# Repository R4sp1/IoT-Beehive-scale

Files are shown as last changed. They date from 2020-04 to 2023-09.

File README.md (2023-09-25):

# IoT Beehive scale :honeybee:

### What is it?

  The aim of this graduation work is to manufacture bee hive weight measuring equipment with
  information transfer via Internet of Things network Sigfox. It deals with Internet of Things
  technology, weight sensors, energy saving in battery powered devices, PCB designing in the
  EAGLE program and the production of device to monitor the current weight, temperature and
  humidity inside and around the bee hive. Information processing is provided by
  microcontroller ATmega 328U placed on the Arduino pro mini and programmed in Wiring
  language in Arduino IDE.

### Why is it?

  The repository contains code for my high school graduation project and the SOČ competition (High school project competition).

### Co je to?

  Cílem této maturitní práce je výroba zařízení pro měření hmotnosti včelího úlu s přenosem
  informací pomocí sítě internetu věcí Sigfox. Zabývá se technologií internetu věcí, váhových
  senzorů, úsporou energie v rámci napájení na baterii, návrhem plošného spoje v programu
  EAGLE a výrobou funkčního zařízení pro sledování aktuální váhy, teploty a vlhkosti uvnitř
  a v okolí včelího úlu. Zpracování informací je zajištěno mikrokontrolerem ATmega 328U
  umístěném na Arduinu pro mini a naprogramovaném v jazyce Wiring v programu Arduino
  IDE.

### Proč je to?

  Repozitář obsahuje kód k maturitnímu projektu a k soutěži SOČ.

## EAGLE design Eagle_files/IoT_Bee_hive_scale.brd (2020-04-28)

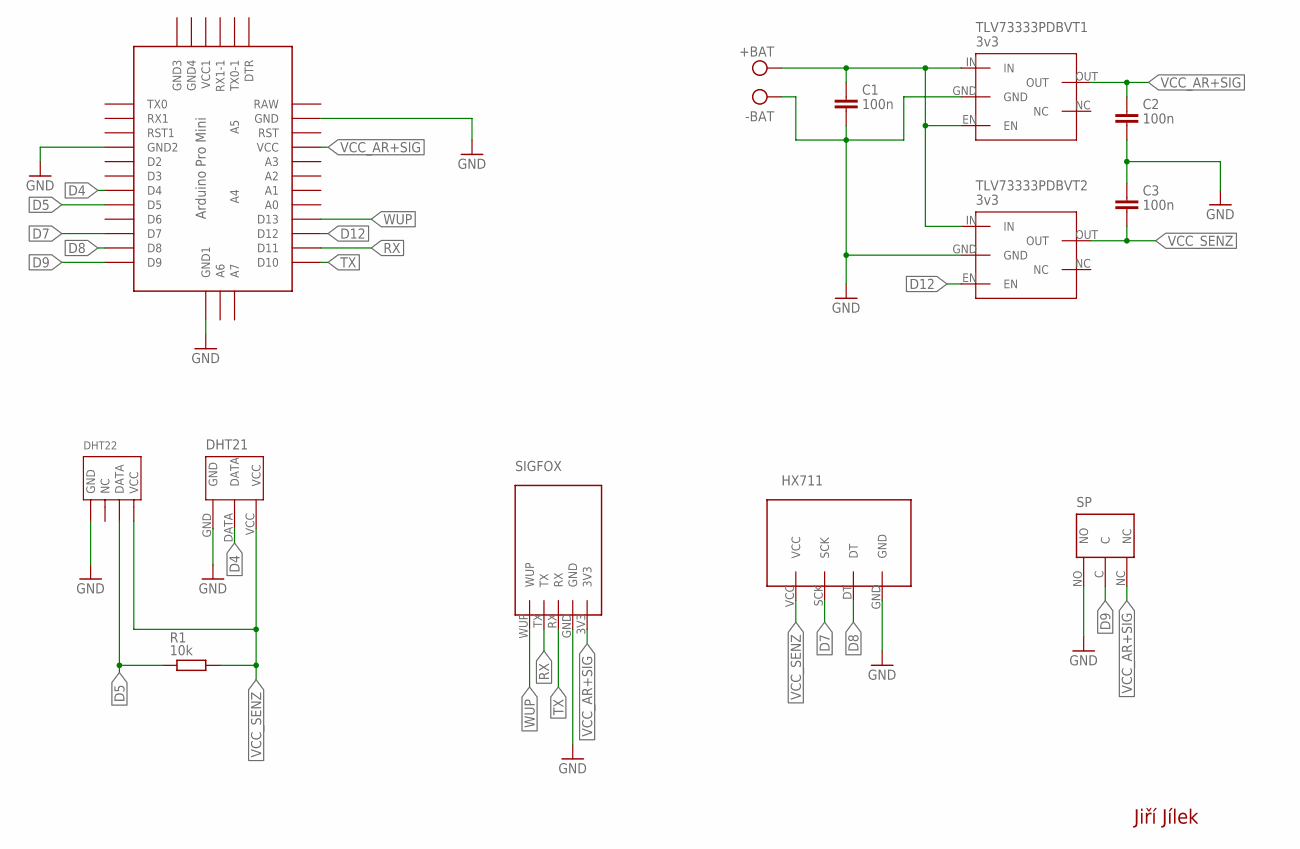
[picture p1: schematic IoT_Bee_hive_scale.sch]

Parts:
+BAT: 3.7V; AK300/2
C1, C2, C3: 100n; C1206
DHT21: 0; DHT21
DHT22: DHT22
HX711: 0; HX711
R1: 10k; R0805
SIGFOX: 0; SIGFOX_NODE
SP: 0; MIKROSP
TLV73333PDBVT1, TLV73333PDBVT2: 3v3; SOT95P280X145-5N
U$1: ABK-PRO-MINI

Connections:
D4: DHT21.DATA, U$1.D4
D5: DHT22.DATA, R1.1, U$1.D5
D7: HX711.SCK, U$1.D7
D8: HX711.DT, U$1.D8
D9: SP.C, U$1.D9
D12: TLV73333PDBVT2.EN, U$1.D12
GND: +BAT.2, C1.2, C2.2, C3.1, DHT21.GND, DHT22.GND, HX711.GND, SIGFOX.GND, SP.NO, TLV73333PDBVT1.GND, TLV73333PDBVT2.GND, U$1.GND, U$1.GND1 (GND2), U$1.GND4 (GND1)
RX: SIGFOX.TX, U$1.D11
TX: SIGFOX.RX, U$1.D10
VCC: +BAT.1, C1.1, TLV73333PDBVT1.EN, TLV73333PDBVT1.IN, TLV73333PDBVT2.IN
VCC_AR+SIG: C2.1, SIGFOX.3V3, SP.NC, TLV73333PDBVT1.OUT, U$1.VCC
VCC_SENZ: C3.2, DHT21.VCC, DHT22.VCC, HX711.VCC, R1.2, TLV73333PDBVT2.OUT
WUP: SIGFOX.WUP, U$1.D13

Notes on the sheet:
+BAT
-BAT
Jiří Jílek

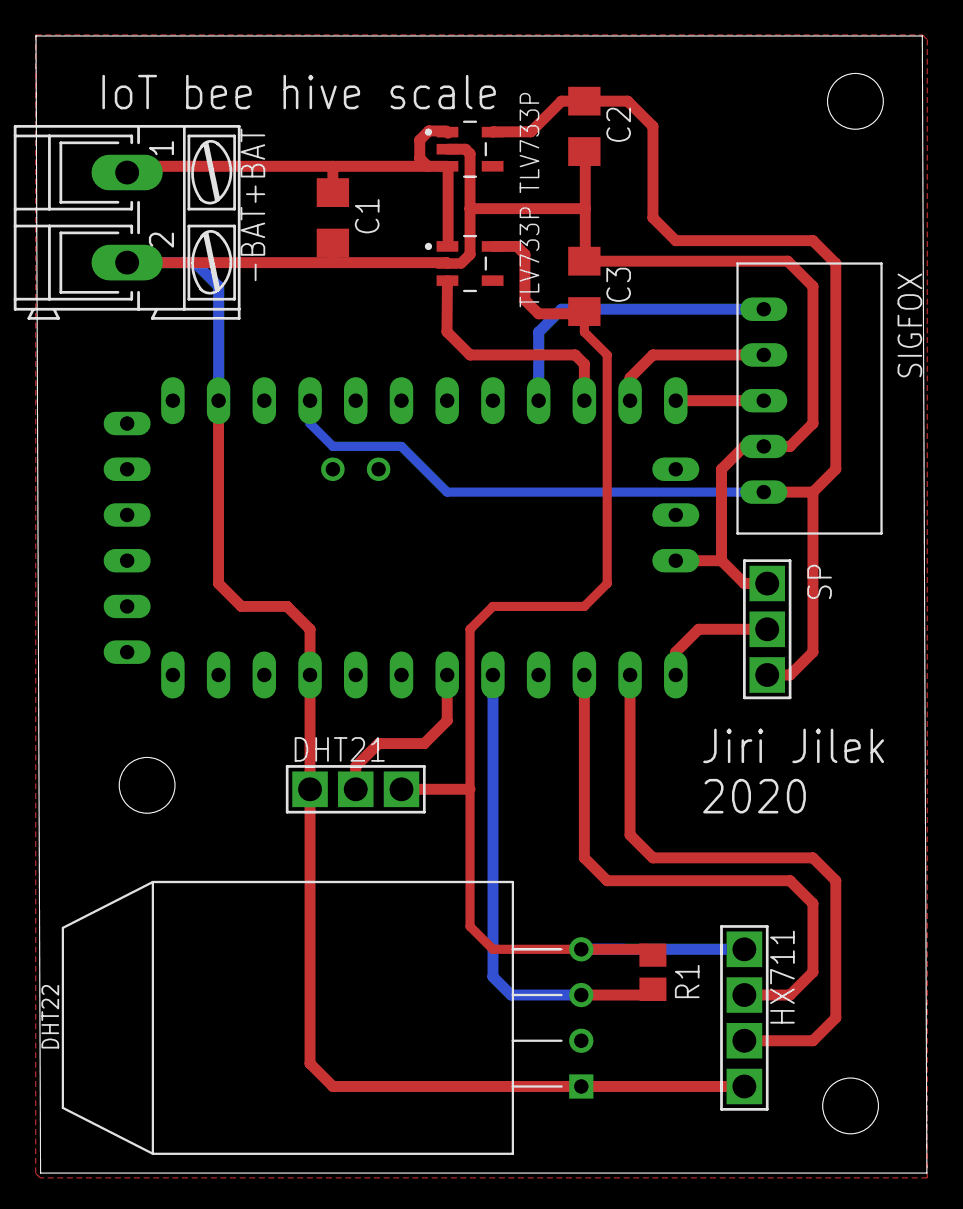
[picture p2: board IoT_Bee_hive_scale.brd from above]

Board: 2 copper layers, 49.5 x 63.2 mm, 13 parts (0 on the bottom side), 13 nets.

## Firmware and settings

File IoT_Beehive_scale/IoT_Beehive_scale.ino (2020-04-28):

#include <SoftwareSerial.h>
#include <DHT.h>
#include <HX711.h>
#include "LowPower.h"

#define TX 10
#define RX 11
#define pinDHTA 4
#define typDHTA DHT21
#define pinDHTB 5
#define typDHTB DHT22
#define calibration_factor -24000.0
#define DT 8
#define SCK 7


int En_volreg = 12;    //enable pin voltage regulatoru
int spinac = 9;       //vstup spínače na hlídání úlu
int state;            //stav pinu 9

SoftwareSerial Sigfox(RX, TX);
DHT DHTA(pinDHTA, typDHTA);
DHT DHTB(pinDHTB, typDHTB);
HX711 scale(DT, SCK);

void setup() {
  Serial.begin(9600);
  Sigfox.begin(9600);
  DHTA.begin();
  DHTB.begin();
  scale.set_scale(calibration_factor);
  pinMode(spinac, INPUT);
  pinMode(En_volreg, OUTPUT);
  delay(1000);
}

void loop() {
  if (Sigfox.available()) {
    Serial.write(Sigfox.read());
  }
  if (Serial.available()) {
    Sigfox.write(Serial.read());
  }

  SigProbudit();
  delay(1000);
  odesliData();
  delay(10000);
  SigUsnout();
  ArSpanek();
  delay(100000);
}


void odesliData() {
  char zprava[12];

  float teplotaA = DHTA.readTemperature();
  unsigned int tepA = (teplotaA + 10) * 10;
  float vlhkostA = DHTA.readHumidity();
  unsigned int vlhA = (vlhkostA);

  float teplotaB = DHTB.readTemperature();
  unsigned int tepB_cela = (teplotaB + 10) * 10;
  float vlhkostB = DHTB.readHumidity();
  unsigned int vlhB = (vlhkostB);

  unsigned int tepB = tepB_cela - tepA + 20;  //zjišťování rozdílu teplot

  int k = 359.64; //číslo musím zjitit samotným scale.get_units potom jen přičítat aby byla bez váhy 0
  float vaha = scale.get_units() + k;
  unsigned int vah = (vaha) * 10;

  delay(500);

  sprintf(zprava, "%03X%02X%02X%02X%03X", tepA, vlhA, tepB, vlhB, vah);
  Sigfox.print("AT$SF=");
  Sigfox.println(zprava);
}


void odeslipoplach() {  //odeslání zprávy o manipulaci
  Sigfox.println("AT$SF=ffffffffffff");
}

void SigUsnout() {  //spánek Sigfox modulu
  Sigfox.println("AT$P=1");
  delay(100);
  digitalWrite(En_volreg, LOW);
}

void SigProbudit() { //probuzení sigfox modulu
  Sigfox.println("\n");
  delay(100);
  digitalWrite(En_volreg, HIGH);
}

void ArSpanek() {  //spánek Arduina
  for (int i = 0; i < 900; i++) {               //i<113=15min, <225=30min, <450=60min, <900=2h, <1350=3h, <1800=4h, <2250=5h, <4500=10h
    LowPower.powerDown(SLEEP_8S, ADC_OFF, BOD_OFF);
    state = digitalRead(spinac);
    if (state == HIGH) {
      SigProbudit();
      delay(1000);
      odeslipoplach();
      delay(5000);
      SigUsnout();
    }
  }
}
